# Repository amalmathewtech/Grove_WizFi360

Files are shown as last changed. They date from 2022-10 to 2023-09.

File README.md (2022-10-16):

# Grove_WizFi360
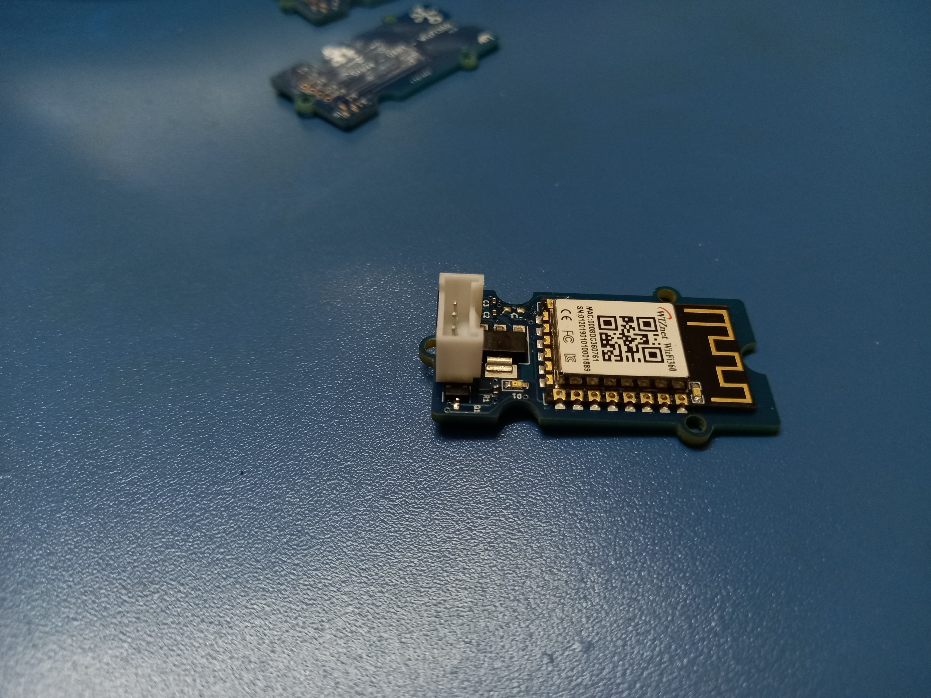
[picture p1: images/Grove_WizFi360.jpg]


Grove - UART - WizFi360 is a serial transceiver module featuring the WizNet's WizFi360 WiFi module .With integrated TCP/IP protocol stack, this module lets your micro-controller interact with WiFi networks with only a few lines of code. Each WizFi360 module comes pre-programmed with an AT command set firmware, meaning you can send simple text commands to control the device.
 
Connectivity is provided via 2.4Ghz wireless connection, WizFi360 is compatible with IEEE802.11 b/g/n standards and supports SoftAP, Station and SoftAP+Station modes.

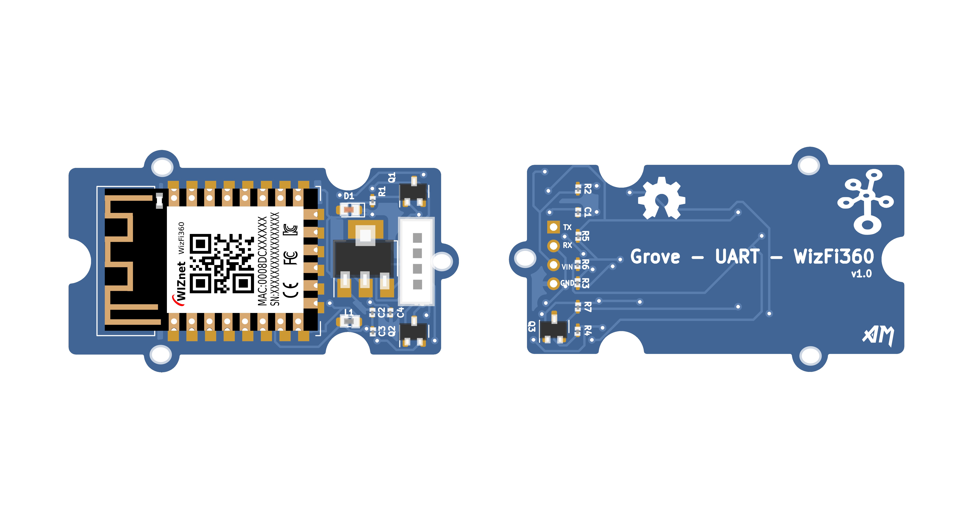
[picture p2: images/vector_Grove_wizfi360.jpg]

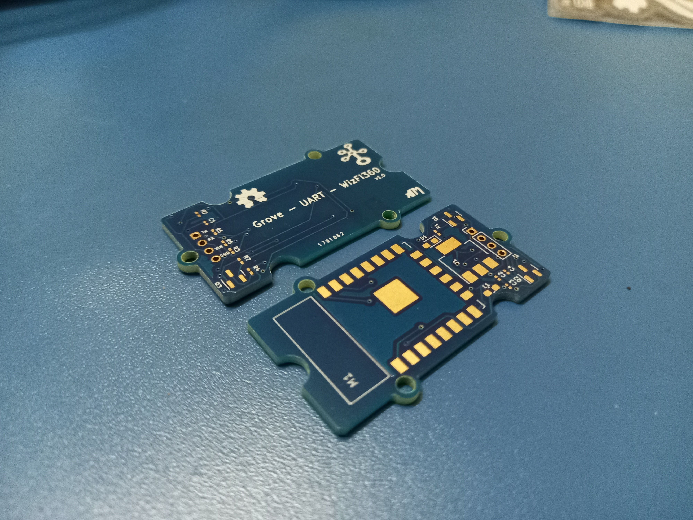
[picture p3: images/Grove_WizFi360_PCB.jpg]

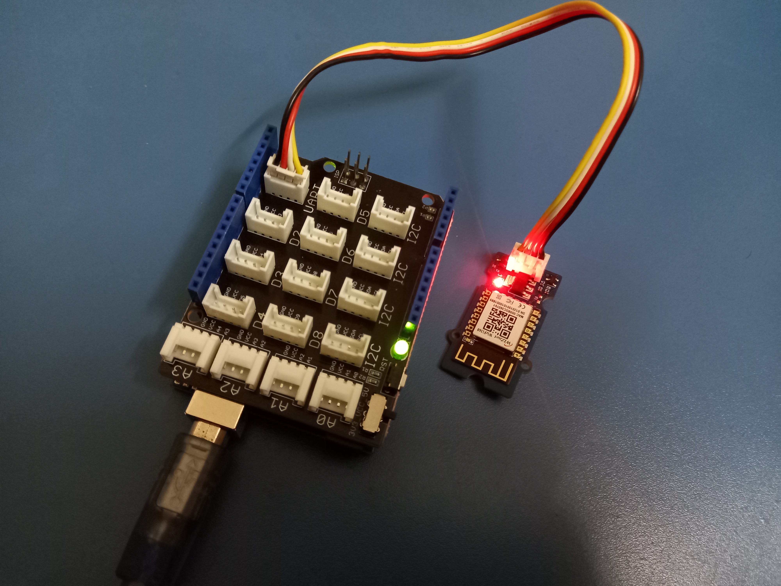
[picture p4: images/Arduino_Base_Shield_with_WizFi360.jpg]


Design Files: This project is designed using Open Source KiCad .Design files are located [here](https://github.com/amalmathewtech/Grove_WizFi360/tree/main/kicad_design_files)

You can download Schematics from [here](https://github.com/amalmathewtech/Grove_WizFi360/tree/main/schematics)

This work is licensed under the MIT License

Made With ❤ in OpenSource

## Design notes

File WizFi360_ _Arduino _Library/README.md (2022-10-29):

## WizFi360 Arduino Library

WIZnet has provided an [**Arduino library**][link-Arduino library and examples for WizFi360] to communicate with the WizFi360 module anda few example sketches that implement basic Wi-Fi applications. 
You can install the WizFi360 library by downloading it as a ZIP file and adding it to your Arduino libraries folder.

This document will guide through a series of steps from configuring development environment to running Arduino
library and examples using the WIZnet's Wi-Fi product - [**WizFi360**][link-wizfi360].

## Development environment configuration

To test the WizFi360 Arduino library & examples, the development environment must be configured to use Arduino platform.

Please note that in this guide examples were configured and tested using **Arduino IDE** in **Windows** environment.

Before starting, download and install the Arduino IDE from the link below.

- [Arduino IDE][link-arduino_ide]

####  How to install an Arduino library
* Download from github 

  Open [**WizFi360 Arduino Library Github page**][link-Arduino library and examples for WizFi360], then you can click on the Clone or download >Download ZIP button to get the library package.
   
   chrome_PdAoKzANiy

* Add the library
  Add ZIP Library  - Since you have downloaded the zip Library, open your Arduino IDE, click on Sketch > Include Library > Add .ZIP Library.
  

Choose the zip file you just downloaded，and if the library install correct, you will see Library added to your libraries in the notice window. Which means the library is installed successfully.


* Check
Then let's check if the library install correctly.

When you add a library successfully, there will be a demo in the Example. In this case, click on File > Example > WizFi360 > ScanNetworks to open an example, click on the Verify button, if there's no error, congratulation, the library is installed perfectly.


### Example testing
This section will guide through testing with ScanNetworks example as an example using Grove_WizFi360 & Arduino Mega 2560 
hardware_connection

* Connect Arduino Mega 2560 to desktop or laptop using USB type B cable.

* Select the type of Arduino board that you are using by the path: Here we will be using Arduino Mega 2560
 
    Tools --> Board -->Arduino AVR Boards -->Arduino Mega or Arduino 2560
    

* Select the correct serial port you are using by the path: Tools --> Serial Port --> for example, COM10


* Upload the ScanNetworks example code
    When there appears "Done uploading", congratulate you upload successfully.
Below is a screenshot of the ScanNetworks example showing the list of detected networks.


[link-wizfi360]: https://docs.wiznet.io/Product/Wi-Fi-Module/WizFi360
[link-Arduino library and examples for WizFi360]: https://github.com/Wiznet/WizFi360_arduino_library
[link-arduino_ide]: https://www.arduino.cc/en/software

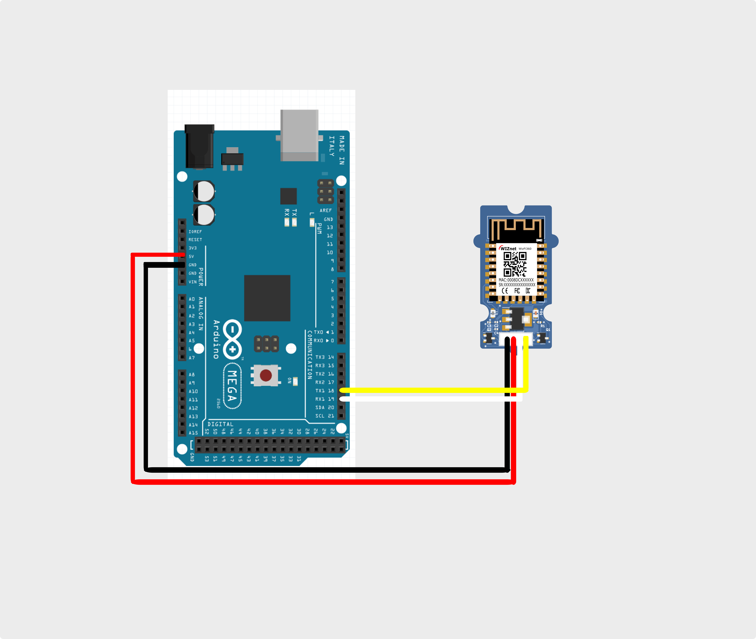
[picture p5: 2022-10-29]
examples/hardware_connection.png

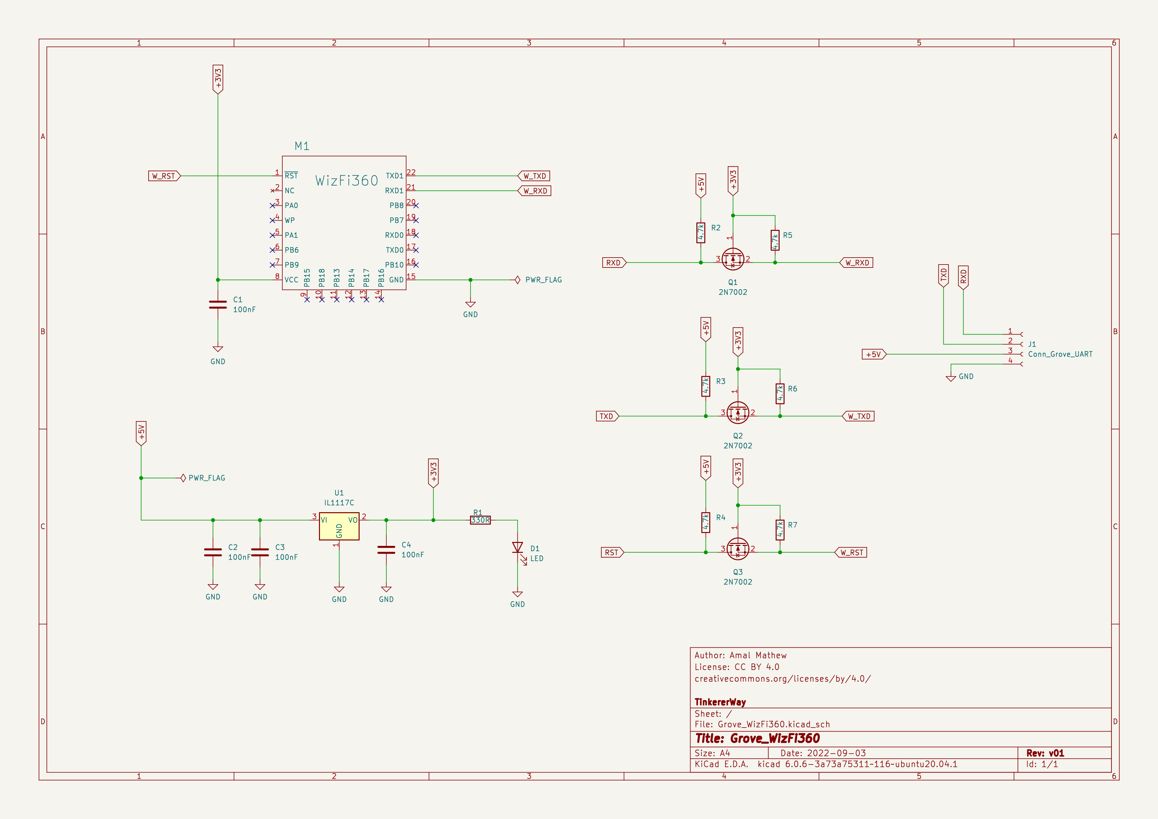
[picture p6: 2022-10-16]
schematics/Grove_WizFi360_kicad_sch.png

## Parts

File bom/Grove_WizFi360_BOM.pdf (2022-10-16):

Filename: Grove_WizFi360_BOM.pdf | TinkererWay (https://tinkererway.com/)
Version: V01 | The Maker Company
Generated: 16/10/2022, 05:23:21

GROVE_WIZFI360 V01 BILL OF MATERIALS
Item # | Reference Designator | Quantity | Value/Part Number | Seeed SKU | Description | Package Referen ce | Datasheet/ Internet Link
1 | C1, C2, C3, C4, | 4 | 100nF-25V | 302010024 | SMD CAP Ceramic 100nF-25V-10%-X7R | 0402 | Datasheet (https://statics3.seeedstudio.com/fusion/opl/datasheet/302010024.pdf)
2 | D1 | 1 | Red LED | 304090042 | LED-SMD Red Diffused | 0603 | Datasheet (https://statics3.seeedstudio.com/fusion/opl/datasheet/304090042.pdf)
3 | J1 | 1 | Grove Female Header -DIP-4P-2.0mm | 110990030 | Grove Female Header - DIP-4P-2.0mm | DIP | Internet Link (https://www.seeedstudio.com/Grove-Universal-4-pin-connector.html)
4 | M1 | 1 | WizFi360-PA | | WIZnet WiFi Module | SMD | https://www.wiznet.
io/productitem/wizfi360/ (https://www.wiznet.io/product-item/wizfi360/)
5 | Q1, Q2, Q3, | 3 | 2N7002 | N Channel MOSFET | SOT23 | Datasheet (https://www.mouser.in/datasheet/2/427/70226-1765504.pdf)
6 | R1 | 1 | 330R | 1/10W-5% SMD | 0402
7 | R2, R3, R4, R5, R6, R7 | 6 | 4.7k | 1/10W-5% SMD | 0402
8 | U1 | 1 | IL1117C-33ET | IL1117C-33ET ,3.3V 1A CMOS LDO, SOT223 Package | SOT223 | Datasheet (http://www.iksemi.com/pds/app/20180118_IL1117_Application.pdf)
9 | | 1 | PCB | 2-Layer, 20mm x 40mm, PCB Color: Blue, Silk Screen: White

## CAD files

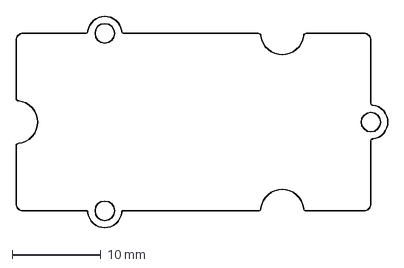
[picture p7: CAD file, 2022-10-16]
kicad_design_files/dxf_file/Grove-Plug-Vertical1.dxf
41.9 x 23.8 mm

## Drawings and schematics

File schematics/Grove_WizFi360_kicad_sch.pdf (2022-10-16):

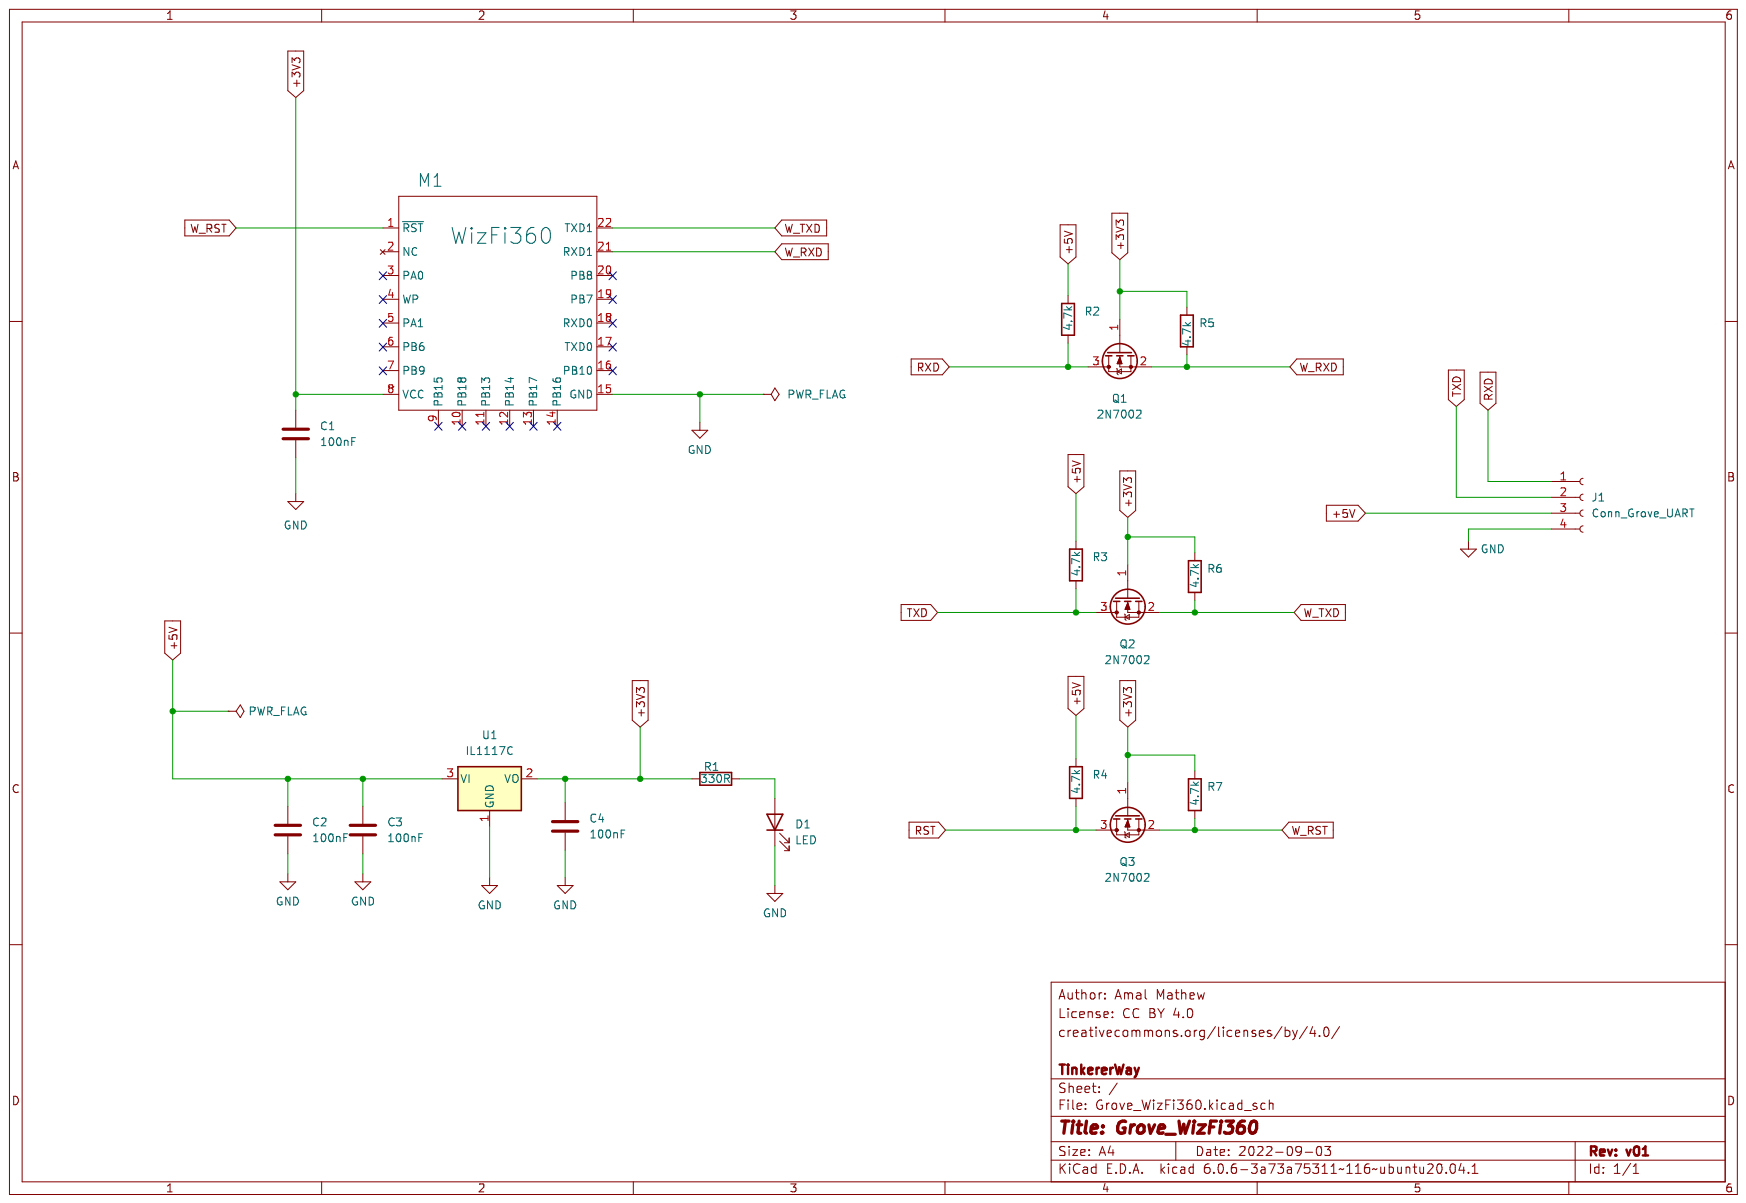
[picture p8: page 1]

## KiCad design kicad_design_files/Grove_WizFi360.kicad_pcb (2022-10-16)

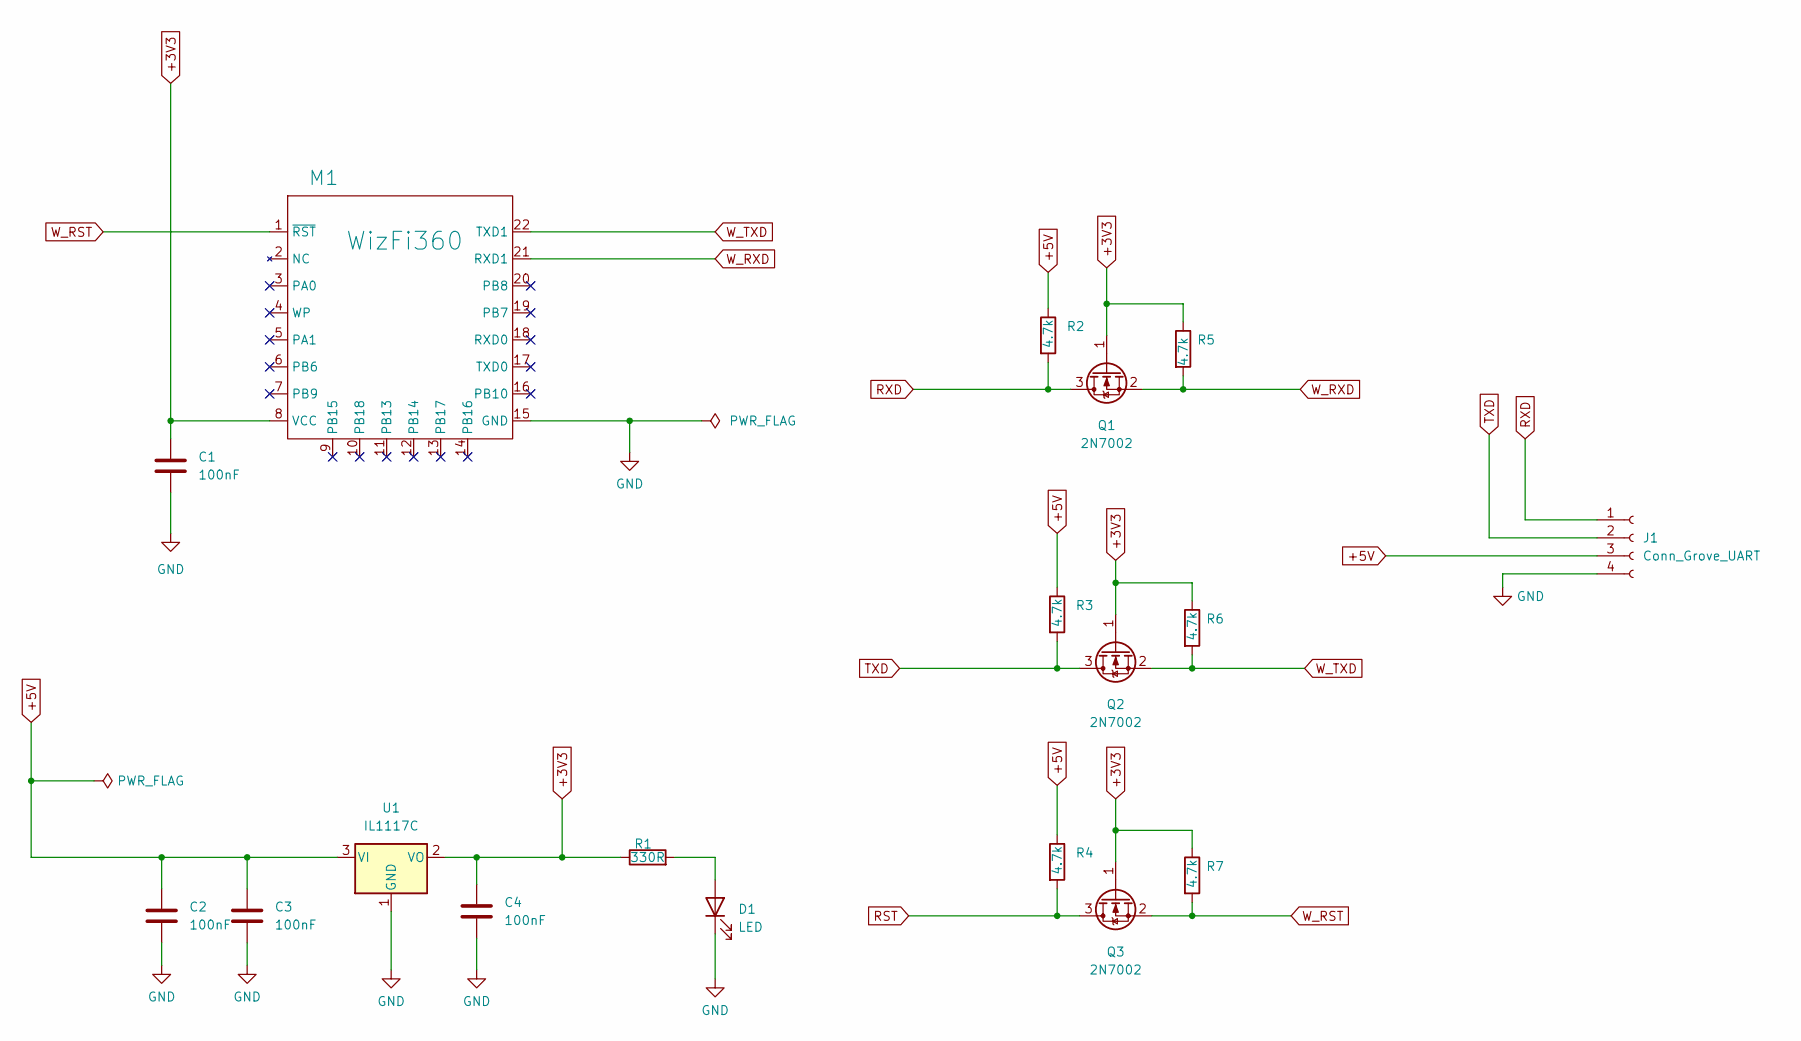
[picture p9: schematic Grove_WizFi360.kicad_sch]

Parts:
C1, C2, C3, C4: 100nF; C_0201_0603Metric
D1: LED; LED_0603_1608Metric_Pad1.05x0.95mm_HandSolder
J1: Conn_Grove_UART; PinHeader_1x04_P2.00mm_Vertical
M1: WizFi360; WizFi360-PA
Q1, Q2, Q3: 2N7002; SOT-23
R1: 330R; R_0201_0603Metric_Pad0.64x0.40mm_HandSolder
R2, R3, R4, R5, R6, R7: 4.7k; R_0201_0603Metric_Pad0.64x0.40mm_HandSolder
U1: IL1117C; SOT-223-3_TabPin2

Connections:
+3V3: C1.1, C4.1, M1.8 (VCC), Q1.1 (G), Q2.1 (G), Q3.1 (G), R1.1, R5.1, R6.1, R7.1, U1.2 (VO); also elsewhere on the board
+5V: C2.1, C3.1, J1.3, R2.1, R3.1, R4.1, U1.3 (VI); also elsewhere on the board
GND: C1.2, C2.2, C3.2, C4.2, D1.1 (K), J1.4, M1.15 (GND), U1.1 (GND)
unnamed: D1.2 (A), R1.2
RST: Q3.3 (D), R4.2
RXD: J1.1, Q1.3 (D), R2.2
TXD: J1.2, Q2.3 (D), R3.2
W_RST: M1.1 (~RST), Q3.2 (S), R7.2
W_RXD: M1.21 (RXD1), Q1.2 (S), R5.2
W_TXD: M1.22 (TXD1), Q2.2 (S), R6.2

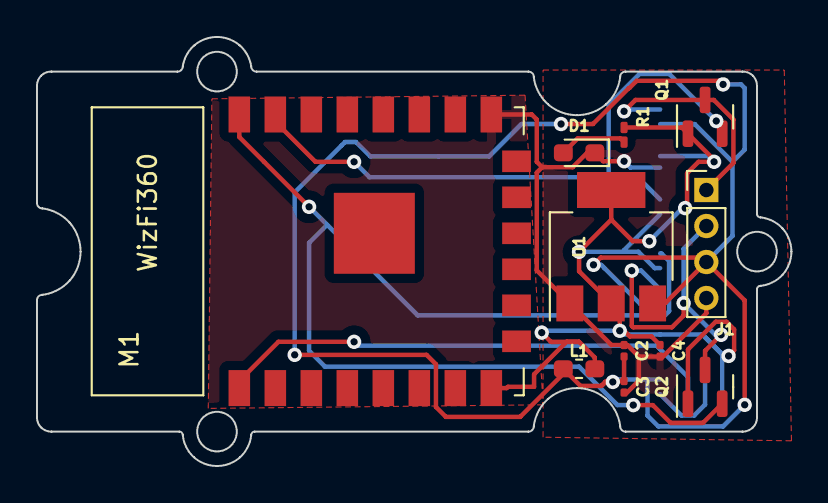
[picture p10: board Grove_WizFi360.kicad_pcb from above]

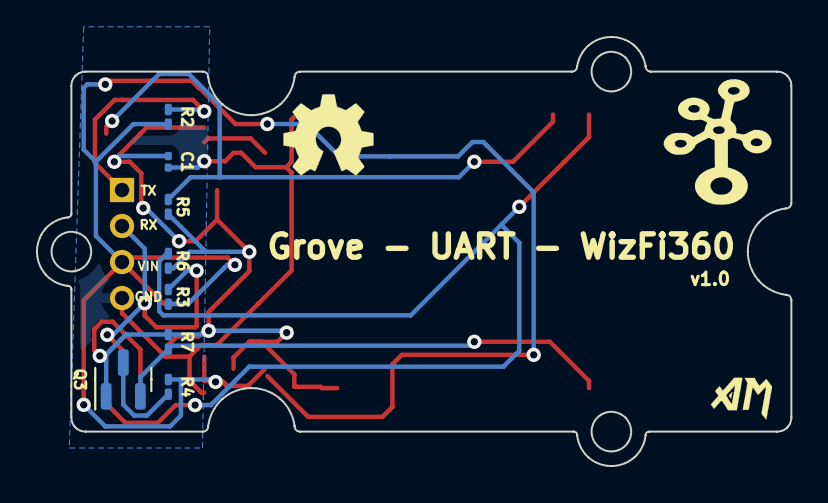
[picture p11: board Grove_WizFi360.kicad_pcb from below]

Board: 2 copper layers, 41.9 x 23.8 mm, 20 parts (9 on the bottom side), 10 nets.

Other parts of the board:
***: LOGO; grove_logo
L1: HH-1M1608-; L_0603_1608Metric_Pad1.05x0.95mm_HandSolder

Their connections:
+3V3: L1.2; also elsewhere on the board
+5V: L1.1; also elsewhere on the board

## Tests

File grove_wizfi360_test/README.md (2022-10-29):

## Test Procedure for Grove_WizFi360

Requirements:
* Python 3.4 and newer
* Windows 7 or newer 
* pySerial module must be installed on the system -  refer. https://gist.github.com/amalmathewtech/1e4a11d97bc5d41f21c79aa1f142e390

Hardware Setup :


* Connect USB to Serial Converter to Computer
* Modify the serial port number in ```grove_wizfi360_at_command_test.py``` python script  
You can use following python script to find your serial port number to ease your work.

Refer - https://github.com/amalmathewtech/quick-reference/blob/main/serial_spotter_py.py

* Run the python script
* If there are some issue with the grove_wizfi360 you will get following message
  
* 	If you are getting response as below, it indicates test passed.


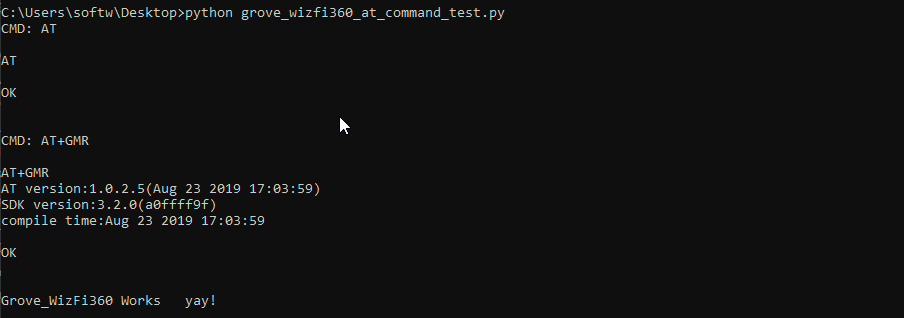
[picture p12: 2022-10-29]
grove_wizfi360_test/wizfi360_test_pass_message.png

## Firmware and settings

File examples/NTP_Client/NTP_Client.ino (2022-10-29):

/*
 Grove_WizFi360 example: NTP_Client

  Get the time from a Network Time Protocol (NTP) time server
 
  •	Grove_WizFi360-TX: 18th pin of Arduino Mega
  •	Grove_WizFi360-RX: 19th pin of Arduino Mega
  •	Grove_WizFi360-GND: GND pin of Arduino Mega
  •	Grove_WizFi360-VIN: 5V pin of Arduino Mega

   This code is in the public domain.
  
*/


/* Baudrate */
#define SERIAL_BAUDRATE   115200
#define SERIAL1_BAUDRATE  115200

#define DEBUG true


// Send AT Commands and  print response
String sendData(String command, const int timeout, boolean debug)
{
    String response = "";                                             
    Serial1.print(command);                                          
    long int time = millis();                                      
    while( (time+timeout) > millis())                                 
    {      
      while(Serial1.available())                                      
      {
        char c = Serial1.read();                                     
        response+=c;                                                  
      }  
    }    
    if(debug)                                                        
    {
      Serial.print(response);
    }    
    return response;                                                  
}

void setup() {
  Serial.begin(SERIAL_BAUDRATE);
  Serial1.begin(SERIAL1_BAUDRATE);
  
  sendData("AT+RST\r\n", 2000, DEBUG); 
  sendData("AT\r\n", 1000, DEBUG); 

  sendData("AT+CWMODE_CUR=1\r\n", 1000, DEBUG); 
  sendData("AT+CWDHCP_CUR=1,1\r\n", 1000, DEBUG);

  sendData("AT+CWJAP=\"PUT YOUR SSID\",\"PUT YOUR PASSWORD\"\r\n", 5000, DEBUG);        //connect to the WiFi network.
  //sendData("AT+CWJAP=\"SSID\",\"12345678\"\r\n", 5000, DEBUG);        
  sendData("AT+CIPSTA_CUR?\r\n", 3000, DEBUG);
  sendData("AT+CIPSNTPCFG=1,8\r\n", 2000, DEBUG); 
  sendData("AT+CIPSNTPTIME?\r\n", 2000, DEBUG);  // Time in China

}

void loop() {
  
}

                  

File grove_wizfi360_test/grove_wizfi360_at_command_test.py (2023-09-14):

# Python code to test Basic AT Commands on WizFi360

import serial, time
import sys

#change serial port number accordingly 
wizfi360 = serial.Serial("COM8",  115200, timeout=0)



#Functions
def sendCMD_waitResp(cmd):
    print("CMD: " + cmd)
    wizfi360.write(cmd.encode())
    waitResp()
    print()
    
def waitResp():
    resp = b""
    time.sleep(0.1)
    if wizfi360.in_waiting:
        resp = b"".join([resp, wizfi360.read(1024)])
    if(resp == b''):
        sys.exit("Error!  :  WizFi360 is not present or not responding ")
    else:
        print(resp.decode('utf8'))
    

#AT command Test
sendCMD_waitResp("AT\r\n")     #AT -  Tests AT Startup
sendCMD_waitResp("AT+GMR\r\n") #AT+GMR: Checks Version Information
time.sleep(1)
print("Grove_WizFi360 Works   yay!")

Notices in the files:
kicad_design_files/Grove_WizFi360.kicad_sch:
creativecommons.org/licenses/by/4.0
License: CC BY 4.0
